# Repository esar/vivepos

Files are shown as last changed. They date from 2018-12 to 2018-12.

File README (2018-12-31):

This repository contains the PCB design and firmware for
a stanalone position sensor for use with the VIVE VR system.

 * 4 sensors, 30 positions/s each
 * Totally standalone, works out lighthouse positions for itself
 * No configuration, apply power... get position data
 * Accounts for gravity direction using accelerometer data from lighthouses
 * Output sent via USB serial and/or UART
 * Running on a 20MHz AVR

For latest version and full description, go to:
http://hacks.esar.org.uk/vive-position-sensor/

How to use:

1) Manufacture the board that can be found in the 'board' directory 
   (CADSoft Eagle format).
2) Edit Makefile and change paths to tools:
   CCDEVS, CCINC, CC, OBJCOPY, OBJDUMP
3) Run 'make' to build the firmware
4) Write firmware to board, e.g.:
   avrdude -c jtag2updi -P /dev/ttyACM1 -p m3209 -U flash:w:image.hex
5) Connect USB (or power+UART) to board
6) The board should start outputing position data shortly after
   the lighthouses become visible to it.
7) Use the solve-lighthouse.py script to pretty print the data stream:
   ./solve-lighthouse.py --dump-pos --dump-sensor=0 /dev/ttyACM0

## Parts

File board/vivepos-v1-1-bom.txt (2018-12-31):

Resistors (all 1% 0402 SMD)
===========================
33R        R7,R8,R21,R34,R35,R48,R57,R58,R71,R80,R81,R94
560R       R6,R33,R56,R79
100K       R17,R24,R25,R26,R44,R67,R90,R101,R102,R103
10K        R1,R2,R28,R29,R51,R52,R74,R75,R97,R98,R99,R100
12K        R18,R45,R68,R91
15K        R9,R14,R36,R41,R59,R64,R82,R87
1K         R11,R15,R27,R38,R42,R61,R65,R84,R88,R104
1K2        R23,R50,R73,R96
1K5        R4,R31,R54,R77
2K7        R12,R16,R39,R43,R62,R66,R85,R89
56K        R19,R20,R46,R47,R69,R70,R92,R93
5K6        R22,R49,R72,R95
6K8        R10,R13,R37,R40,R60,R63,R83,R86
8K2        R3,R5,R30,R32,R53,R55,R76,R78

Capacitors (Ceramic 0402 SMD)
=====================
100nF      C1,C2,C5,C7,C9,C11,C12,C13,C14,C15,C18,C20,C22,C24,C25,C26,C29,C31,C33,C35,C36,C37,C40,C42,C44,C46
100pF      C3,C10,C16,C23,C27,C34,C38,C45
1nF        C4,C6,C8,C17,C19,C21,C28,C30,C32,C39,C41,C43,C49,C50

Capacitors (other)
=================
2.2uF    Ceramic 0805                                                     C47
4.7uF    16V Tantalum (Kemet B45196E3475K209, no longer manufactured)     C48

Diodes
======
Photo-diode BPW32S             D1,D2,D3,D4
Schottky    PMEG3010EJ.115     D5,D6

Semiconductors
==============
Microcontroller ATMEGA3209     U$2
Quad Comparator LM339PT        IC2
Dual NPN/PNP    MBT3946DWDW    T13,T14,T15,T16,T17,T18,T19,T20,T21,T22,T23,T24
USB Serial      MCP2221        U$1
3V3 regulator   TPS76933DBVT   IC1

Connectors
==========
PINHD-1X2                     JP1
PINHD-1X3                     JP3
USB Amphenol 10103594-0001LF  JP2

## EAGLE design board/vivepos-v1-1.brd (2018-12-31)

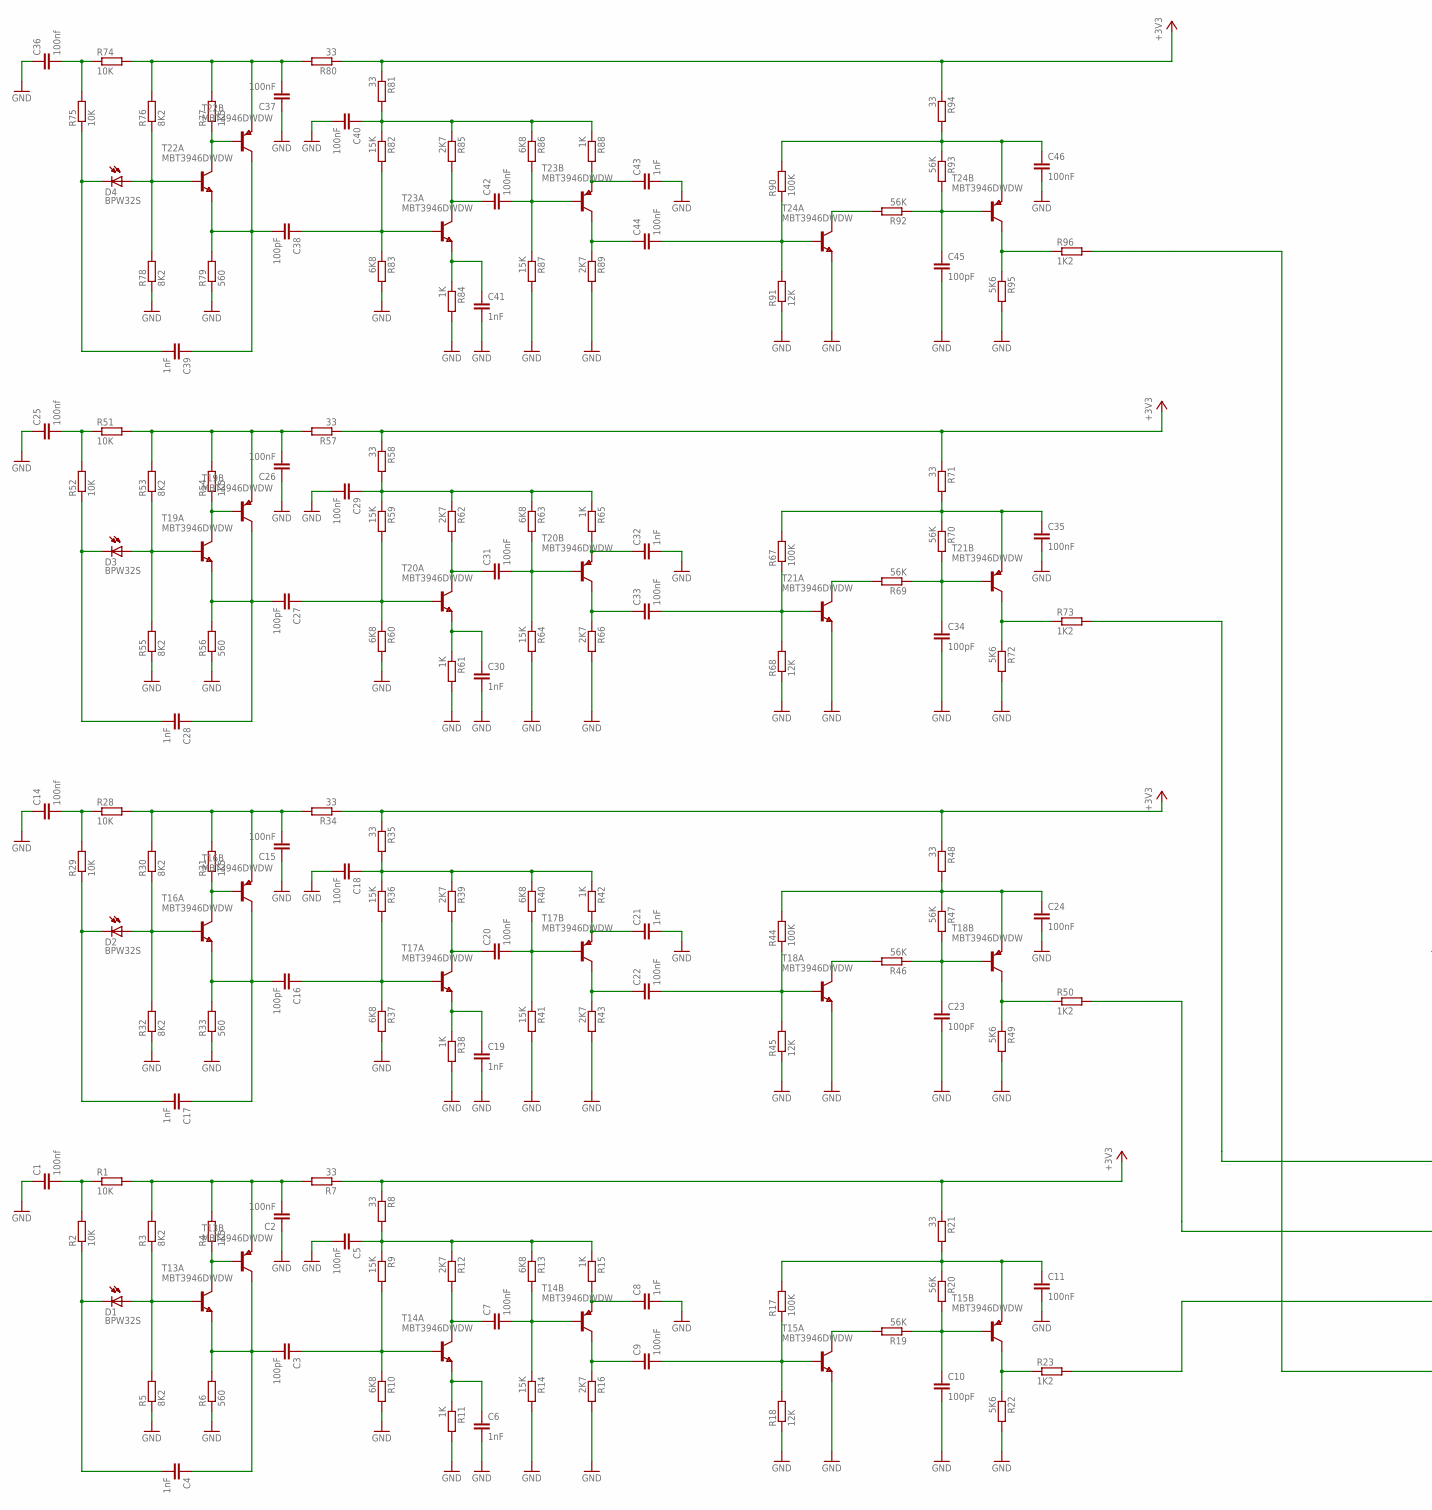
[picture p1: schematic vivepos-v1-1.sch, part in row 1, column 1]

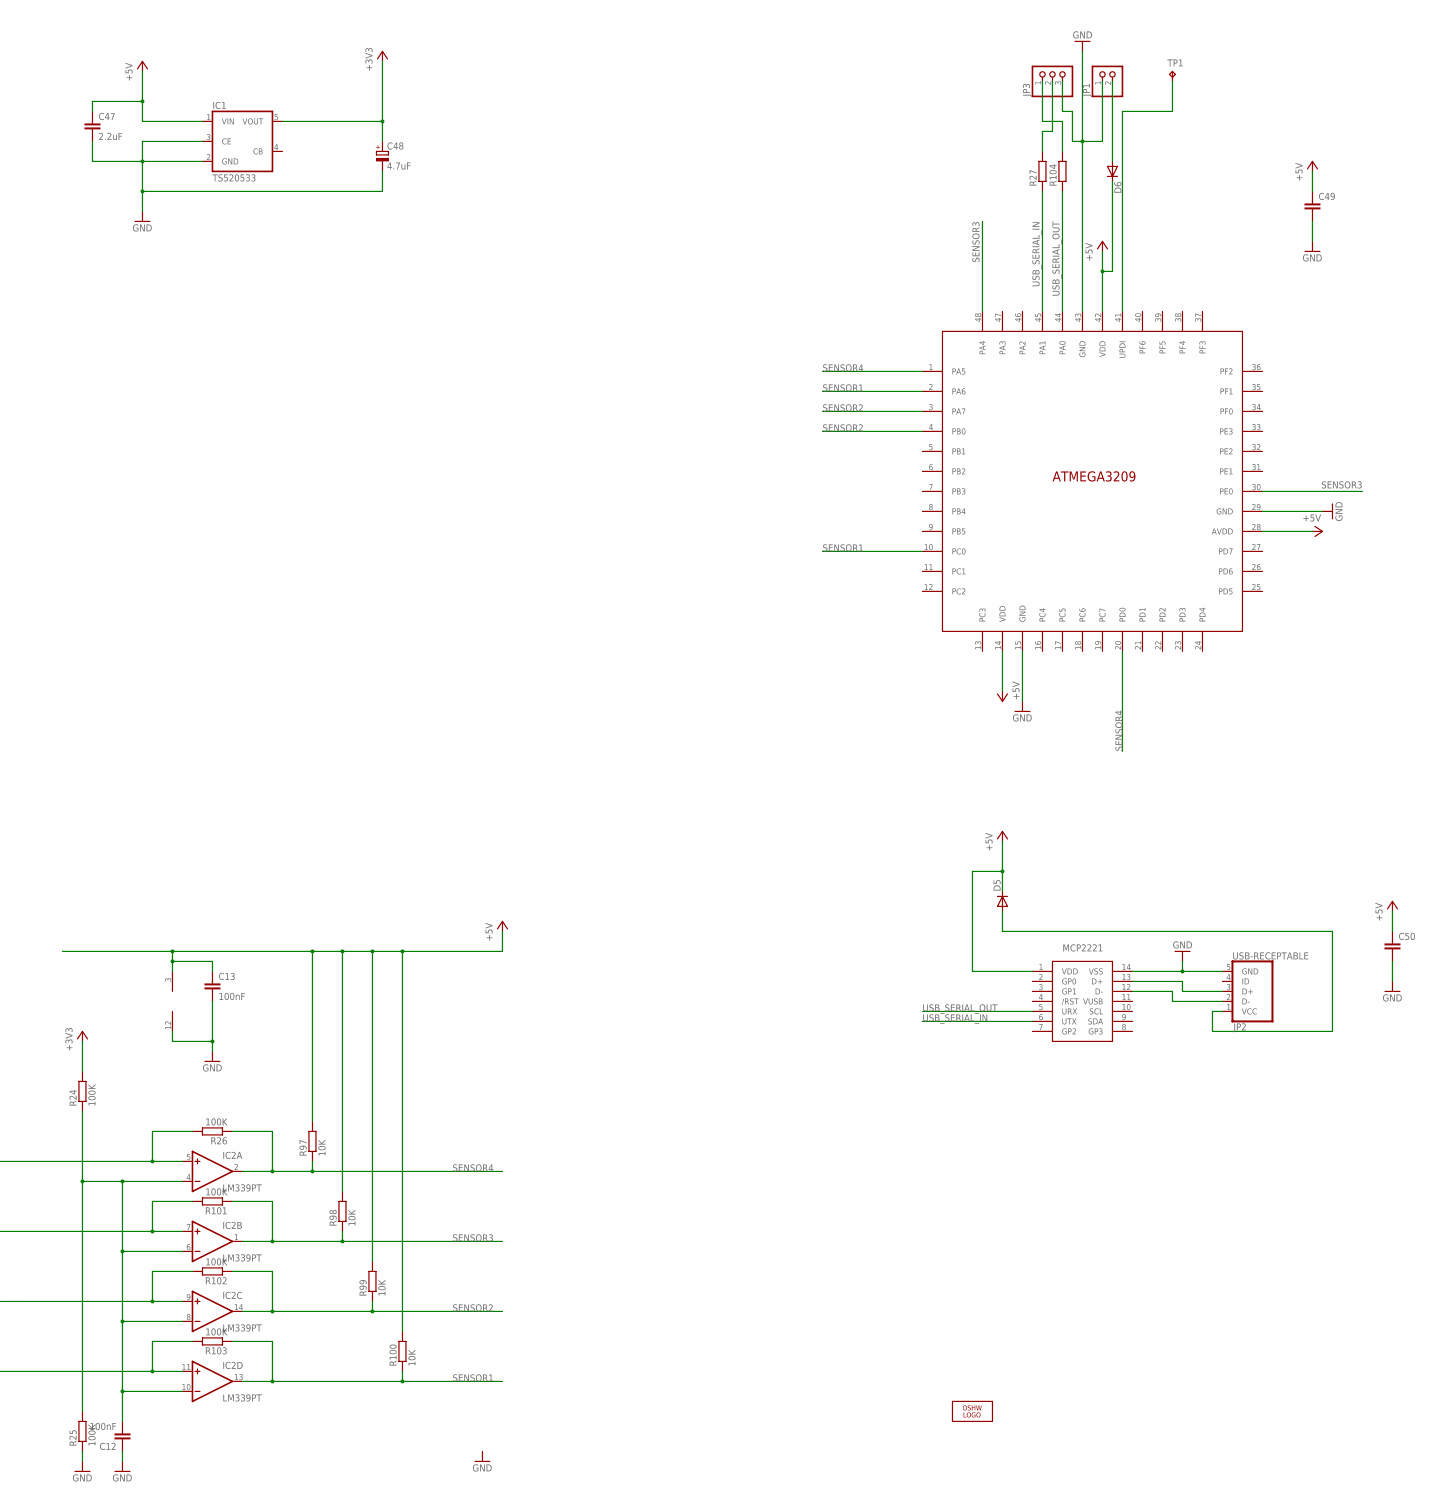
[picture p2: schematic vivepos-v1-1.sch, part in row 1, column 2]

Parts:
C1, C14, C25, C36: 100nf; C0402
C2, C5, C7, C9, C11, C12, C13, C15, C18, C20, C22, C24, C26, C29, C31, C33, C35, C37, C40, C42, C44, C46: 100nF; C0402
C3, C10, C16, C23, C27, C34, C38, C45: 100pF; C0402
C4, C6, C8, C17, C19, C21, C28, C30, C32, C39, C41, C43: 1nF; C0402
C47: 2.2uF; C0805
C48: 4.7uF; B/3528-21R
C49: C-EUC0402; C0402
C50: C-EUC0603; C0603
D1, D2, D3, D4: BPW32S; BPW34S
D5, D6: DIODE-SOD323-W; SOD323-W
IC1: TS520533; SOT25
IC2: LM339PT; TSSOP14
JP1: PINHD-1X2; 1X02
JP2: USB-RECEPTABLE; FCI-10103594-0001LF
JP3: PINHD-1X3; 1X03
LOGO1: OSHW_LOGO_FILLX0200-NT; OSHW_FILLX200_NOTEXT
R1, R2, R28, R29, R51, R52, R74, R75, R97, R98, R99, R100: 10K; R0402
R3, R5, R30, R32, R53, R55, R76, R78: 8K2; R0402
R4, R31, R54, R77: 1K5; R0402
R6, R33, R56, R79: 560; R0402
R7, R8, R21, R34, R35, R48, R57, R58, R71, R80, R81, R94: 33; R0402
R9, R14, R36, R41, R59, R64, R82, R87: 15K; R0402
R10, R13, R37, R40, R60, R63, R83, R86: 6K8; R0402
R11, R15, R38, R42, R61, R65, R84, R88: 1K; R0402
R12, R16, R39, R43, R62, R66, R85, R89: 2K7; R0402
R17, R24, R25, R26, R44, R67, R90, R101, R102, R103: 100K; R0402
R18, R45, R68, R91: 12K; R0402
R19, R20, R46, R47, R69, R70, R92, R93: 56K; R0402
R22, R49, R72, R95: 5K6; R0402
R23, R50, R73, R96: 1K2; R0402
R27, R104: R-EU_R0402; R0402
T13, T14, T15, T16, T17, T18, T19, T20, T21, T22, T23, T24: MBT3946DWDW; SOT363_PHILIPS
TP1: TPTP15R; TP15R
U$1: MCP2221; SOIC14
U$2: ATMEGA3209; TQFP48

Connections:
+3V3: C48.+, IC1.5 (VOUT), R7.1, R8.1, R21.1, R24.2, R34.1, R35.1, R48.1, R57.1, R58.1, R71.1, R80.1, R81.1, R94.1
+5V: C13.1, C47.1, C49.1, C50.1, D5.C, D6.C, IC1.1 (VIN), IC2.3 (V+), R97.2, R98.2, R99.2, R100.2, U$1.1 (VDD), U$2.14 (VDD), U$2.28 (AVDD), U$2.42 (VDD)
GND: C1.1, C2.1, C5.2, C6.2, C8.2, C10.2, C11.2, C12.1, C13.2, C14.1, C15.1, C18.2, C19.2, C21.2, C23.2, C24.2, C25.1, C26.1, C29.2, C30.2, C32.2, C34.2, C35.2, C36.1, C37.1, C40.2, C41.2, C43.2, C45.2, C46.2, C47.2, C48.-, C49.2, C50.2, IC1.2 (GND), IC1.3 (CE), IC2.12 (GND), JP1.1, JP2.5 (GND), JP3.3, R5.1, R6.1, R10.2, R11.2, R14.2, R16.2, R18.1, R22.2, R25.1, R32.1, R33.1, R37.2, R38.2, R41.2, R43.2, R45.1, R49.2, R55.1, R56.1, R60.2, R61.2, R64.2, R66.2, R68.1, R72.2, R78.1, R79.1, R83.2, R84.2, R87.2, R89.2, R91.1, R95.2, T15.1 (E), T18.1 (E), T21.1 (E), T24.1 (E), U$1.14 (VSS), U$2.15 (GND), U$2.29 (GND), U$2.43 (GND)
unnamed: C1.2, R1.1, R2.2
unnamed: C2.2, R1.2, R3.2, R4.2, R7.2, T13.4 (E)
unnamed: R4.1, T13.5 (B), T13.6 (C)
unnamed: D1.A, R3.1, R5.2, T13.2 (B)
unnamed: C3.2, C4.1, R6.2, T13.1 (E), T13.3 (C)
unnamed: C5.1, R8.2, R9.1, R12.1, R13.1, R15.1
unnamed: C3.1, R9.2, R10.1, T14.2 (B)
unnamed: C7.1, R12.2, T14.6 (C)
unnamed: C6.1, R11.1, T14.1 (E)
unnamed: C8.1, R15.2, T14.4 (E)
unnamed: C7.2, R13.2, R14.1, T14.5 (B)
unnamed: C9.1, R16.1, T14.3 (C)
unnamed: C4.2, D1.K (C), R2.1
unnamed: C9.2, R17.1, R18.2, T15.2 (B)
unnamed: C11.1, R17.2, R20.1, R21.2, T15.4 (E)
unnamed: C10.1, R19.1, R20.2, T15.5 (B)
unnamed: R19.2, T15.6 (C)
unnamed: R22.1, R23.1, T15.3 (C)
unnamed: IC2.9 (+IN), R23.2, R102.2
unnamed: C12.2, IC2.4 (-IN), IC2.6 (-IN), IC2.8 (-IN), IC2.10 (-IN), R24.1, R25.2
unnamed: C14.2, R28.1, R29.2
unnamed: D6.A, JP1.2
unnamed: C15.2, R28.2, R30.2, R31.2, R34.2, T16.4 (E)
unnamed: R31.1, T16.5 (B), T16.6 (C)
unnamed: D2.A, R30.1, R32.2, T16.2 (B)
unnamed: C16.2, C17.1, R33.2, T16.1 (E), T16.3 (C)
unnamed: D5.A, JP2.1 (VCC)
unnamed: C18.1, R35.2, R36.1, R39.1, R40.1, R42.1
unnamed: C16.1, R36.2, R37.1, T17.2 (B)
unnamed: C20.1, R39.2, T17.6 (C)
unnamed: C19.1, R38.1, T17.1 (E)
unnamed: C20.2, R40.2, R41.1, T17.5 (B)
unnamed: C21.1, R42.2, T17.4 (E)
unnamed: C22.1, R43.1, T17.3 (C)
unnamed: C17.2, D2.K (C), R29.1
unnamed: C22.2, R44.1, R45.2, T18.2 (B)
unnamed: C24.1, R44.2, R47.1, R48.2, T18.4 (E)
unnamed: C23.1, R46.1, R47.2, T18.5 (B)
unnamed: R46.2, T18.6 (C)
unnamed: R49.1, R50.1, T18.3 (C)
unnamed: C25.2, R51.1, R52.2
unnamed: C26.2, R51.2, R53.2, R54.2, R57.2, T19.4 (E)
unnamed: R54.1, T19.5 (B), T19.6 (C)
unnamed: D3.A, R53.1, R55.2, T19.2 (B)
unnamed: C27.2, C28.1, R56.2, T19.1 (E), T19.3 (C)
unnamed: TP1.TP, U$2.41 (UPDI)
unnamed: C29.1, R58.2, R59.1, R62.1, R63.1, R65.1
unnamed: C27.1, R59.2, R60.1, T20.2 (B)
unnamed: C31.1, R62.2, T20.6 (C)
unnamed: C30.1, R61.1, T20.1 (E)
unnamed: C31.2, R63.2, R64.1, T20.5 (B)
unnamed: C32.1, R65.2, T20.4 (E)
unnamed: C33.1, R66.1, T20.3 (C)
unnamed: C28.2, D3.K (C), R52.1
unnamed: C33.2, R67.1, R68.2, T21.2 (B)
unnamed: C35.1, R67.2, R70.1, R71.2, T21.4 (E)
unnamed: C34.1, R69.1, R70.2, T21.5 (B)
unnamed: R69.2, T21.6 (C)
unnamed: R72.1, R73.1, T21.3 (C)
unnamed: JP3.2, R27.2
unnamed: C36.2, R74.1, R75.2
unnamed: C37.2, R74.2, R76.2, R77.2, R80.2, T22.4 (E)
unnamed: R77.1, T22.5 (B), T22.6 (C)
unnamed: D4.A, R76.1, R78.2, T22.2 (B)
unnamed: C38.2, C39.1, R79.2, T22.1 (E), T22.3 (C)
unnamed: JP3.1, R104.2
unnamed: C40.1, R81.2, R82.1, R85.1, R86.1, R88.1
unnamed: C38.1, R82.2, R83.1, T23.2 (B)
unnamed: C42.1, R85.2, T23.6 (C)
unnamed: C41.1, R84.1, T23.1 (E)
unnamed: C42.2, R86.2, R87.1, T23.5 (B)
unnamed: C43.1, R88.2, T23.4 (E)
unnamed: C44.1, R89.1, T23.3 (C)
unnamed: C39.2, D4.K (C), R75.1
unnamed: C44.2, R90.1, R91.2, T24.2 (B)
unnamed: C46.1, R90.2, R93.1, R94.2, T24.4 (E)
unnamed: C45.1, R92.1, R93.2, T24.5 (B)
unnamed: R92.2, T24.6 (C)
unnamed: R95.1, R96.1, T24.3 (C)
unnamed: JP2.3 (D+), U$1.13 (D+)
unnamed: JP2.2 (D-), U$1.12 (D-)
unnamed: IC2.7 (+IN), R50.2, R101.2
unnamed: IC2.11 (+IN), R96.2, R103.2
unnamed: IC2.5 (+IN), R26.2, R73.2
SENSOR1: IC2.13 (OUT), R100.1, R103.1, U$2.2 (PA6), U$2.10 (PC0)
SENSOR2: IC2.14 (OUT), R99.1, R102.1, U$2.3 (PA7), U$2.4 (PB0)
SENSOR3: IC2.1 (OUT), R98.1, R101.1, U$2.30 (PE0), U$2.48 (PA4)
SENSOR4: IC2.2 (OUT), R26.1, R97.1, U$2.1 (PA5), U$2.20 (PD0)
USB_SERIAL_IN: R27.1, U$1.6 (UTX), U$2.45 (PA1)
USB_SERIAL_OUT: R104.1, U$1.5 (URX), U$2.44 (PA0)

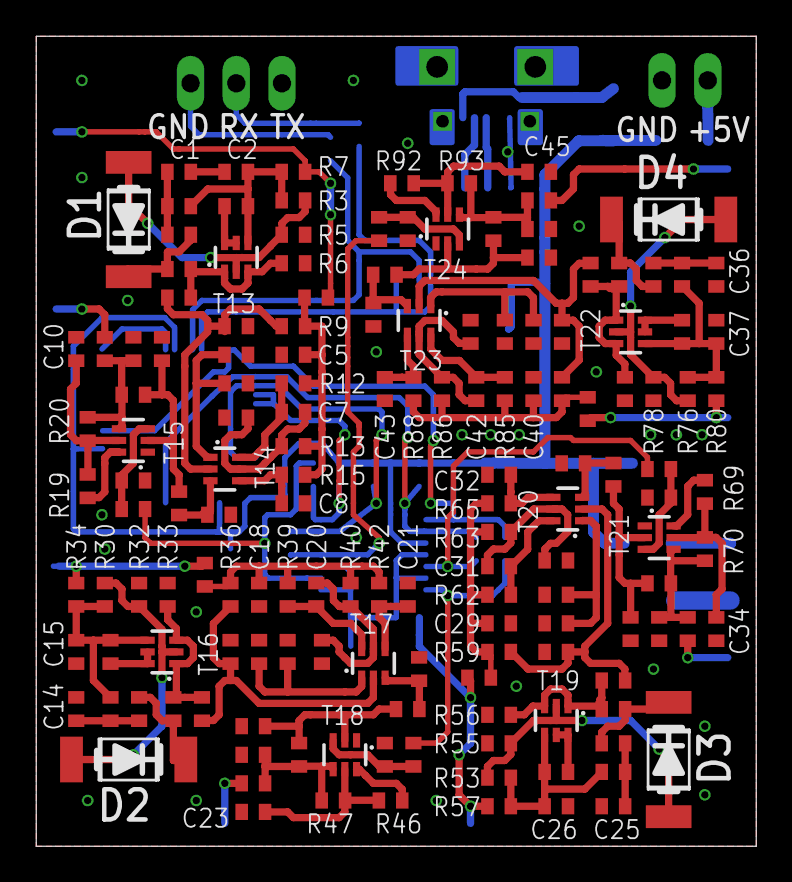
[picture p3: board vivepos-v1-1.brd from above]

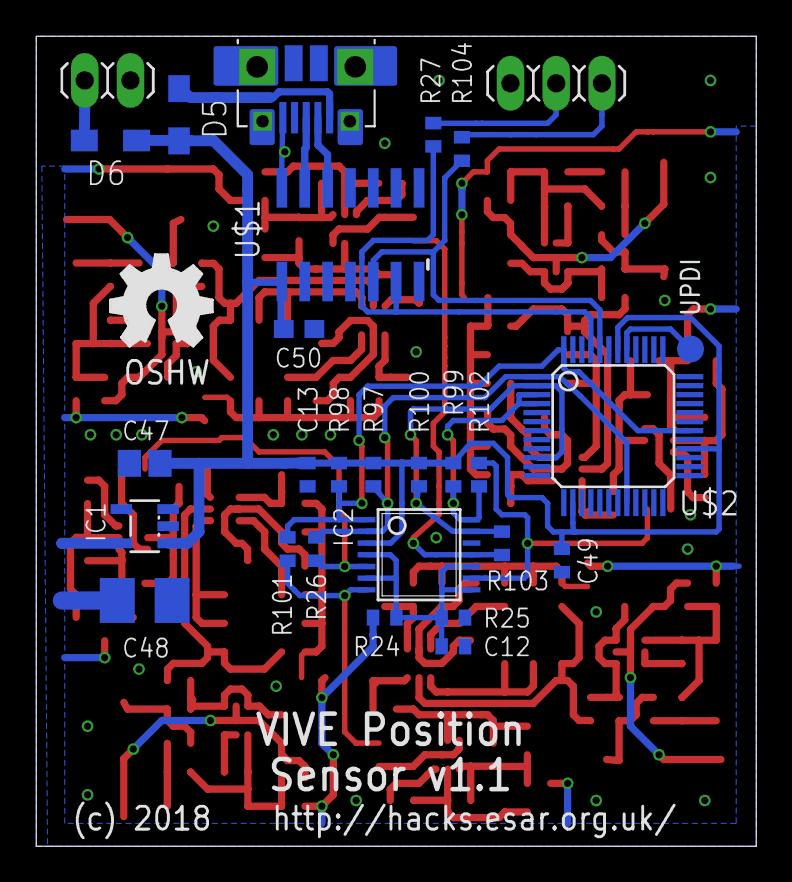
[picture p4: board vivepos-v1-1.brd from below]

Board: 2 copper layers, 40.0 x 45.0 mm, 181 parts (29 on the bottom side), 93 nets.

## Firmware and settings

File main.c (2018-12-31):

/*

   Copyright (C) 2018 Stephen Robinson
  
   This file is part of vivepos
  
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
*/

#include <string.h>
#include <stdio.h>
#include <math.h>

#include <avr/io.h>
#include <avr/interrupt.h>

#include "vivepos.h"
#include "uart.h"


#define SOLVE_LIGHTHOUSE_INTERVAL    1200 /*7200*/ /* 60 seconds */
#define SEND_LIGHTHOUSE_INTERVAL     1200  /*  5 seconds */

#define NUM_SOLUTIONS                2

#define SOLUTION_VALID()             (g_activeSolution < NUM_SOLUTIONS)

// TODO: Use RTC

static lighthouse_solution_t g_solutions[NUM_SOLUTIONS];
static uint8_t      g_activeSolution = -1;
static ootx_msg_t   g_lighthouseOotx[NUM_LIGHTHOUSES];
static sensor_t     g_sensors[NUM_SENSORS];
static uint16_t     g_sweepCount = 0;
static uint8_t      g_time = 0;



ISR(TCA0_OVF_vect)
{
	++g_time;
	TCA0.SINGLE.INTFLAGS |= 1;
}

// NOTE: TCBx.INTFLAGS is cleared by reading TCBx.CCMP
#define TCB_ISR(tcb, sensor)    \
	ISR(TCB##tcb##_INT_vect, ISR_NAKED) \
	{ \
		/* g_sensors[0].riseTime = TCB0.CCMP; */ \
		/* g_sensors[0].state = SENSOR_STATE_RISEN; */ \
		asm volatile( \
			       /* "sbi  0x15, 5         \n\t" */ \
			        "push r24             \n\t" \
			        "push r30             \n\t" \
			        "push r31             \n\t" \
			        "ldi  r30, lo8(%1)    \n\t"  /* Z = &g_sensors[x] */ \
			        "ldi  r31, hi8(%1)    \n\t" \
			        "lds  r24, %0         \n\t"  /* r24 = TCBx_CCMPL */ \
			        "std  Z+1, r24        \n\t" \
		       	        "lds  r24, %0+1       \n\t"  /* r24 = TCBx_CCMPH */ \
			        "std  Z+2, r24        \n\t" \
			        "ldi  r24, 1          \n\t"  /* r24 = SENSOR_STATE_RISEN */ \
			        "st   Z,   r24        \n\t" \
			        "pop  r31             \n\t" \
			        "pop  r30             \n\t" \
			        "pop  r24             \n\t" \
			       /* "cbi  0x15, 5         \n\t" */ \
			        "reti                 \n\t" \
			        : : "i" (_SFR_IO_ADDR(TCB##tcb##_CCMP)), "i" (&g_sensors[sensor])); \
	}
TCB_ISR(0, 1);
TCB_ISR(1, 0);
TCB_ISR(2, 3);
TCB_ISR(3, 2);


ISR(PORTA_PORT_vect)
{
	// grab the timer count and flags ASAP
	uint16_t count = TCB0.CNT;
	uint8_t  triggered = VPORTA.INTFLAGS;

//VPORTF.OUT |= 64;
	// clear the flags so we know if another edge
	// arrives while we're working
	VPORTA.INTFLAGS |= triggered;

	while(triggered)
	{
		// Make sure we've got all the rising edges first
		if(TCB0.INTFLAGS & 1)
			TCB0_INT_vect();
		if(TCB1.INTFLAGS & 1)
			TCB1_INT_vect();
		if(TCB2.INTFLAGS & 1)
			TCB2_INT_vect();
		if(TCB3.INTFLAGS & 1)
			TCB3_INT_vect();

		if(triggered & (1 << (4+2)))
		{
			if(g_sensors[0].state == SENSOR_STATE_RISEN)
			{
				g_sensors[0].fallTime = count;
				g_sensors[0].state = SENSOR_STATE_FALLEN;
			}
		}
		if(triggered & (1 << (4+3)))
		{
			if(g_sensors[1].state == SENSOR_STATE_RISEN)
			{
				g_sensors[1].fallTime = count;
				g_sensors[1].state = SENSOR_STATE_FALLEN;
			}
		}
		if(triggered & (1 << (4+0)))
		{
			if(g_sensors[2].state == SENSOR_STATE_RISEN)
			{
				g_sensors[2].fallTime = count;
				g_sensors[2].state = SENSOR_STATE_FALLEN;
			}
		}
		if(triggered & (1 << (4+1)))
		{
			if(g_sensors[3].state == SENSOR_STATE_RISEN)
			{
				g_sensors[3].fallTime = count;
				g_sensors[3].state = SENSOR_STATE_FALLEN;
			}
		}

		count = TCB0.CNT;
		triggered = VPORTA.INTFLAGS;
		VPORTA.INTFLAGS |= triggered;
	}
//VPORTF.OUT &= ~64;
}

// decodePulseWidth returns:
//     PULSE_TYPE_SWEEP (0x10)   for short sweep pulses
//     0x00 -> 0x07              for data from valid sync pulses
//     PULSE_TYPE_INVALID (0xf0) for pulses that are too long
//
// Pulse encoding info originally from: 
// https://github.com/nairol/LighthouseRedox/blob/master/docs/Light%20Emissions.md
//
//                      documented     observed     tick window with  
// skip | data | axis |  length uS | center ticks | (x - 309) / 51.2 
// -----+------+------+------------+--------------+-------------------
//    0 |    0 |    0 |       62.5 |    334 +/- 5 |       309 -> 359 
//    0 |    0 |    1 |       72.9 |    386 +/- 4 |       360 -> 410 
//    0 |    1 |    0 |       83.3 |    438 +/- 5 |       411 -> 461 
//    0 |    1 |    1 |       93.8 |    490 +/- 5 |       462 -> 512 
//    1 |    0 |    0 |      104.0 |    542 +/- 4 |       513 -> 563 
//    1 |    0 |    1 |      115.0 |    594 +/- 5 |       564 -> 615 
//    1 |    1 |    0 |      125.0 |    646 +/- 5 |       616 -> 666 
//    1 |    1 |    1 |      135.0 |    698 +/- 4 |       667 -> 717 
//
// Using 5Mhz clock, tick is 0.2uS
// 52 ticks between centers: (x * 5) / 256 = x / 51.2 = close enough
// width - 309 centers observed data in the length windows
//
uint8_t decodePulseWidth(int16_t width)
{
	uint8_t result;

	width = width - 296;
	if(width < 0)
		return PULSE_TYPE_SWEEP;
	result = ((width << 2) + width) >> 8;
	if(result > 7)
		result = PULSE_TYPE_INVALID;
	return result;
}

void ootxAddBit(ootx_t* ootx, uint8_t bit)
{
	if((bit & 1) && ootx->shiftRegister == 0 && ootx->frameBit == 0)
	{
		// got preamble
		ootx->pos = 0;
		ootx->length = 0;
		ootx->shiftCount = 0;
	}
	else if(ootx->shiftCount == 17)
	{
		ootx->shiftCount = 0;
		if((bit & 1) == 0)// || ootx->frameBit == 0)
			ootx->length = 0xff;  // abort

		// end of word
		if(ootx->length == 0)
		{
			ootx->length = (ootx->shiftRegister << 8) | (ootx->shiftRegister >> 8);
			ootx->length += 2;  // add checksum to length
		}
		else if(ootx->length != 0xff)
		{
			if(ootx->pos < ootx->length && ootx->pos < sizeof(ootx->data))
			{
				ootx->data[ootx->pos++] = ootx->shiftRegister >> 8;
				ootx->data[ootx->pos++] = ootx->shiftRegister & 0xFF;
			}
			else
			{
				// TODO: validate checksum
				ootx->validLength = ootx->length;
				ootx->length = 0xff;
			}
		}
	}

	ootx->frameBit = ootx->shiftRegister >> 15;
	ootx->shiftRegister = (ootx->shiftRegister << 1) | ((bit & 1));
	ootx->shiftCount = (ootx->shiftCount + 1);
}

uint8_t pollSensor(uint8_t sensorIndex)
{
	uint16_t now;
	sensor_t* sensor = &g_sensors[sensorIndex];

	if(sensor->state == SENSOR_STATE_RISEN)
	{
		now = TCA0.SINGLE.CNT;
		if(now - sensor->riseTime > SENSOR_TIMEOUT)
		{
			sensor->fallTime = sensor->riseTime + 1;
			sensor->state = SENSOR_STATE_FALLEN;
//printf("TOT\r\n");
//VPORTF.OUT |= 16;
//VPORTF.OUT &= ~16;
		}
	}

	if(sensor->state == SENSOR_STATE_FALLEN)
	{
		uint16_t riseTime;
		uint16_t width;
		uint8_t  data;

		riseTime = sensor->riseTime;
		width = sensor->fallTime - sensor->riseTime;
		sensor->state = SENSOR_STATE_IDLE;

		data = decodePulseWidth(width);

		//printf("%u, %u, %u, %u\r\n", sensorIndex, riseTime, width, data);

		if(data == PULSE_TYPE_INVALID)
		{
			printf("LRG %u\r\n", width);
			return 0;
		}

		if(data == PULSE_TYPE_SWEEP)
		{
			if(sensor->currentAngle < NUM_ANGLES)
			{
				uint16_t delta = riseTime - sensor->startTime;

				// note: compiler should reduce to angleTicks[sensor->currentAngle]
				sensor->angleTicks[sensor->currentAngle >> 1][sensor->currentAngle & 1] += delta;
 				sensor->angleTicks[sensor->currentAngle >> 1][sensor->currentAngle & 1] >>= 1;
				sensor->angleRadians[sensor->currentAngle >> 1][sensor->currentAngle & 1] = ((scalar_t)delta - SWEEP_CENTER_IN_TICKS) * (M_PI / SWEEP_180_IN_TICKS);
				              
				sensor->currentAngle = ANGLE_INVALID;
			}
		}
		else
		{
			uint16_t ticksSinceFirstPulse = riseTime - sensor->firstPulseTime;
			uint8_t lighthouse;

			if((ticksSinceFirstPulse >= MICROSECONDS_IN_TICKS(300) && 
			    ticksSinceFirstPulse <= MICROSECONDS_IN_TICKS(500)))
			{
				lighthouse = 1;
				sensor->firstPulseTime = riseTime - MICROSECONDS_IN_TICKS(400);
			}
			else
			{
				// Doesn't fit timing of second lighthouse, so it's either the first
				// or we're out of sync and might as well consider it the first
				lighthouse = 0;
				sensor->firstPulseTime = riseTime;
			}

			if(!PULSE_DATA_SKIP(data))
			{
				sensor->currentAngle = (lighthouse << 1) | PULSE_DATA_AXIS(data);
				sensor->startTime = riseTime;
			}

			ootxAddBit(&sensor->ootx[lighthouse], PULSE_DATA_DATA(data));
		}
	}
	else
	{
		now = TCA0.SINGLE.CNT;
		if(now - sensor->firstPulseTime > MICROSECONDS_IN_TICKS(8333 + 200))
		{
			// No pulse for more than 8333uS so move sensor->firstPulseTime
			// on by one cycle to try and stay locked while we're out of sight
			// of the lighthouses
			sensor->firstPulseTime += MICROSECONDS_IN_TICKS(8333);
		}
		else if(now - sensor->firstPulseTime > MICROSECONDS_IN_TICKS(600) &&
		        now - sensor->firstPulseTime < MICROSECONDS_IN_TICKS(800))
		{
			// Let the caller know that we're in the processing window
			// after the sync pulses where we don't expect more than one
			// further pulse (the sweep) in this cycle. This means we can
			// risk not being called for a while, because we won't miss
			// a pulse if more than one occur before we're next called

			// Also let them know which sweep we're on so that they
			// can synchronise processing angles when a whole set is
			// complete
			return sensor->currentAngle + 1;
		}
	}

	return 0;
}

scalar_t calcTotalTriangulationError(lighthouse_solution_t* solution)
{
	uint8_t i;
	vec3_t result;
	scalar_t distance;
	scalar_t total = 0;

	for(i = 0; i < NUM_SENSORS; ++i)
	{
		calcPosition(solution->lighthouses,
		             g_sensors[i].angleRadians[MASTER][AXIS0],
		             g_sensors[i].angleRadians[MASTER][AXIS1],
		             g_sensors[i].angleRadians[SLAVE][AXIS0],
		             g_sensors[i].angleRadians[SLAVE][AXIS1],
		             result,
		             &distance);
		total += fabs(distance);
	}

	return total;
}

uint8_t processWindowSolveLighthouse()
{
	static uint16_t last = 0;

	if(!SOLUTION_VALID() && g_sweepCount - last > SOLVE_LIGHTHOUSE_INTERVAL)
	{
		// Go ahead if we have everything that we need
		if(g_lighthouseOotx[0].length > 0 && 
		   g_lighthouseOotx[1].length > 0)
		{
			uint8_t index = (g_activeSolution + 1) % NUM_SOLUTIONS;

			printf("S:Solving\r\n");
//VPORTF.OUT |= 2;
			// Takes ~100mS to solve
			solveLighthouse(&g_solutions[index], g_sensors, g_lighthouseOotx);
//VPORTF.OUT &= ~2;

			if(g_solutions[index].totalError < (scalar_t)1.0)
				g_solutions[index].totalError = calcTotalTriangulationError(&g_solutions[index]);
			printf("S:Solution Error %.02f\r\n", g_solutions[index].totalError);

			if(g_solutions[index].totalError < (scalar_t)1.0)
			{
				printf("S:Running\r\n");
				g_activeSolution = index;
			}

			last = g_sweepCount;
			return 1;
		}

	}

	return 0;
}

void sendLighthouse(uint8_t index)
{
	printf("L:%u,%.1f,%.1f,%.1f,%f,%f,%f,%f,%f,%f,%f,%f,%f\r\n", index,
	       (float)g_solutions[g_activeSolution].lighthouses[index].origin[0],
	       (float)g_solutions[g_activeSolution].lighthouses[index].origin[1],
	       (float)g_solutions[g_activeSolution].lighthouses[index].origin[2],
	       (float)g_solutions[g_activeSolution].lighthouses[index].rotationMatrix[0],
	       (float)g_solutions[g_activeSolution].lighthouses[index].rotationMatrix[1],
	       (float)g_solutions[g_activeSolution].lighthouses[index].rotationMatrix[2],
	       (float)g_solutions[g_activeSolution].lighthouses[index].rotationMatrix[3],
	       (float)g_solutions[g_activeSolution].lighthouses[index].rotationMatrix[4],
	       (float)g_solutions[g_activeSolution].lighthouses[index].rotationMatrix[5],
	       (float)g_solutions[g_activeSolution].lighthouses[index].rotationMatrix[6],
	       (float)g_solutions[g_activeSolution].lighthouses[index].rotationMatrix[7],
	       (float)g_solutions[g_activeSolution].lighthouses[index].rotationMatrix[8]);
}

uint8_t processWindowSendLighthouse0()
{
	static uint16_t last = 0;

	if(SOLUTION_VALID() && g_sweepCount - last > SEND_LIGHTHOUSE_INTERVAL)
	{
		// for each lighthouse, approx:
		//     17 fixed chars
		//     7*3 = 21 position chars
		//     9*9 = 81 rotation chars
		// ~119 total bytes per send
		sendLighthouse(0);
		last = g_sweepCount;
		return 1;
	}

	return 0;
}

uint8_t processWindowSendLighthouse1()
{
	static uint16_t last = 0;

	if(SOLUTION_VALID() && g_sweepCount - last > SEND_LIGHTHOUSE_INTERVAL)
	{
		// for each lighthouse, approx:
		//     17 fixed chars
		//     7*3 = 21 position chars
		//     9*9 = 81 rotation chars
		// ~119 total bytes per send
		sendLighthouse(1);
		last = g_sweepCount;
		return 1;
	}

	return 0;
}

uint8_t processWindowSendLighthouseError()
{
	static uint16_t last = 0;

	if(SOLUTION_VALID() && g_sweepCount - last > SEND_LIGHTHOUSE_INTERVAL)
	{
		// ~33 total bytes per send
		printf("E:%.2f,%.2f,%.2f,%.2f,%.2f,%.2f\r\n",
		       (float)g_solutions[g_activeSolution].lighthouses[SLAVE].error.err01,
		       (float)g_solutions[g_activeSolution].lighthouses[SLAVE].error.err02,
		       (float)g_solutions[g_activeSolution].lighthouses[SLAVE].error.err03,
		       (float)g_solutions[g_activeSolution].lighthouses[SLAVE].error.err12,
		       (float)g_solutions[g_activeSolution].lighthouses[SLAVE].error.err13,
		       (float)g_solutions[g_activeSolution].lighthouses[SLAVE].error.err23);
		last = g_sweepCount;
		return 1;
	}

	return 0;
}

uint8_t processWindowCalcAndSendPos()
{
	static uint8_t sensorIndex = 0;
	vec3_t result;
	scalar_t distance;

	if(SOLUTION_VALID())
	{
//VPORTF.OUT |= 2;
		calcPosition(g_solutions[g_activeSolution].lighthouses,
		             g_sensors[sensorIndex].angleRadians[MASTER][AXIS0],
		             g_sensors[sensorIndex].angleRadians[MASTER][AXIS1],
		             g_sensors[sensorIndex].angleRadians[SLAVE][AXIS0],
		             g_sensors[sensorIndex].angleRadians[SLAVE][AXIS1],
		             result,
		             &distance);

		// 32 bytes per send
		printf("P:%u,%.1f,%.1f,%.1f,%.2f\r\n", 
		       sensorIndex,
		       (float)result[0], 
		       (float)result[1], 
		       (float)result[2], 
		       (float)distance);

		sensorIndex = (sensorIndex + 1) % 4;
//VPORTF.OUT &= ~2;

		return 1;
	}

	return 0;
}

// sends average of 29/4 = 7.25 bytes per sweep
uint8_t processWindowSendAngles()
{	
	uint8_t sensorIndex;

	for(sensorIndex = 0; sensorIndex < NUM_SENSORS; ++sensorIndex)
	{
		// 29 bytes per send
		printf("A:%u,%u,%u,%u,%u\r\n", 
		       sensorIndex, 
		       g_sensors[sensorIndex].angleTicks[MASTER][AXIS0], 
		       g_sensors[sensorIndex].angleTicks[MASTER][AXIS1],
		       g_sensors[sensorIndex].angleTicks[SLAVE][AXIS0],
		       g_sensors[sensorIndex].angleTicks[SLAVE][AXIS1]);
	}

	return 1;
}

uint8_t processWindowSaveOotx()
{
	uint8_t sensorIndex;
	uint8_t lighthouseIndex;
	uint8_t doneWork = 0;

	for(sensorIndex = 0; sensorIndex < NUM_SENSORS; ++sensorIndex)
	{
		for(lighthouseIndex = 0; lighthouseIndex < NUM_LIGHTHOUSES; ++lighthouseIndex)
		{
			ootx_t* ootx = &g_sensors[sensorIndex].ootx[lighthouseIndex];

			if(ootx->validLength)
			{
				g_lighthouseOotx[lighthouseIndex].length = ootx->validLength;
				memcpy(g_lighthouseOotx[lighthouseIndex].data, 
				       ootx->data, 
				       ootx->validLength);
				g_lighthouseOotx[lighthouseIndex].isNew = 1;
				ootx->validLength = 0;
				doneWork = 1;

				if(!SOLUTION_VALID())
					printf("S:Got OOTX %u\r\n", lighthouseIndex);
			}
		}
	}

	return doneWork;
}

uint8_t processWindowSendOotx()
{
	uint8_t lighthouseIndex;

	for(lighthouseIndex = 0; lighthouseIndex < NUM_LIGHTHOUSES; ++lighthouseIndex)
	{
		if(g_lighthouseOotx[lighthouseIndex].isNew)
		{
			uint8_t pos;

			// ~72 bytes per send
			printf("D:%u,%u,", 
			       lighthouseIndex, 
			       g_lighthouseOotx[lighthouseIndex].length);
			for(pos = 0; pos < g_lighthouseOotx[lighthouseIndex].length; ++pos)
				printf("%02x", g_lighthouseOotx[lighthouseIndex].data[pos]);
			printf("\r\n");
			g_lighthouseOotx[lighthouseIndex].isNew = 0;
			return 1;
		}
	}

	return 0;
}

int main()
{
	memset(g_sensors, 0, sizeof(g_sensors));

	CCP = 0xd8;             // enable protected register access
	CLKCTRL.MCLKCTRLB = 0;  // no clock prescaler, run at full 20MHz

	EVSYS.CHANNEL1 = EVSYS_GENERATOR_PORT1_PIN0_gc;  // PORTB0 -> CHANNEL1
	EVSYS.USERTCB0 = 2;                              // CHANNEL1 -> TCB0

	EVSYS.CHANNEL2 = EVSYS_GENERATOR_PORT0_PIN0_gc;  // PORTC0 -> CHANNEL2
	EVSYS.USERTCB1 = 3;                              // CHANNEL2 -> TCB1
	
	EVSYS.CHANNEL3 = EVSYS_GENERATOR_PORT1_PIN0_gc;  // PORTD0 -> CHANNEL3
	EVSYS.USERTCB2 = 4;                              // CHANNEL3 -> TCB2

	EVSYS.CHANNEL4 = EVSYS_GENERATOR_PORT0_PIN0_gc;  // PORTE0 -> CHANNEL4
	EVSYS.USERTCB3 = 5;                              // CHANNEL4 -> TCB3

	TCA0.SINGLE.CTRLA = 5;    // enable, CLK/4
	TCA0.SINGLE.INTCTRL = 1;  // enable overflow interrupt

	TCB0.CTRLB   = 2;  // input capture on event
	TCB0.EVCTRL  = 1;  // enable event, rising edge
	TCB0.INTCTRL = 1;  // enable capture interrupt
	TCB0.CTRLA   = 21; // enable, source TCA_CLK, synchronised to TCA

	TCB1.CTRLB   = 2;  // input capture on event
	TCB1.EVCTRL  = 1;  // enable event, rising edge
	TCB1.INTCTRL = 1;  // enable capture interrupt
	TCB1.CTRLA   = 21; // enable, source TCA_CLK, synchronised to TCA

	TCB2.CTRLB   = 2;  // input capture on event
	TCB2.EVCTRL  = 1;  // enable event, rising edge
	TCB2.INTCTRL = 1;  // enable capture interrupt
	TCB2.CTRLA   = 21; // enable, source TCA_CLK, synchronised to TCA

	TCB3.CTRLB   = 2;  // input capture on event
	TCB3.EVCTRL  = 1;  // enable event, rising edge
	TCB3.INTCTRL = 1;  // enable capture interrupt
	TCB3.CTRLA   = 21; // enable, source TCA_CLK, synchronsised to TCA

	TCA0.SINGLE.CTRLESET = 8; // Restart TCA and all synchronised TCBs to get same count in all

	PORTA.PIN4CTRL = 3; // interrupt on falling edge
	PORTA.PIN5CTRL = 3; // interrupt on falling edge
	PORTA.PIN6CTRL = 3; // interrupt on falling edge
	PORTA.PIN7CTRL = 3; // interrupt on falling edge

	PORTF.OUT=0;
	PORTF.DIR=64|32|16|8 |4|2|1;
	//PORTE.OUT=0;
	//PORTE.DIR=8;

	PORTA.OUT = 1;      // Make USART0 pins outputs
        PORTA.DIR = 0xF;
	uartInit();

	sei();

	printf("S:Waiting for OOTX\r\n");
	for(;;)
	{
		uint8_t inProcessingWindow;
		uint8_t sensorIndex;

//VPORTF.OUT |= 8;
		inProcessingWindow = 0;
		for(sensorIndex = 0; sensorIndex < NUM_SENSORS; ++sensorIndex)
		{
			uint8_t result = pollSensor(sensorIndex);
			if(result)
				inProcessingWindow = result;
		}

		if(inProcessingWindow)
		{
			// per sweep we transmit:
			//    item     |  average            | worst case
			//    ---------+---------------------+-----------
			//    position | 32 bytes            | 32 bytes
			//    angles   | 29/4 = 7.25 bytes   | 29 bytes
			//    ootx     | 72/322 = 0.2 bytes  | 72 bytes
			//    l'house  | 119/128 = 0.9 bytes | 119 bytes
			//    TOTAL    | 39.54 bytes         | 32+119 = 151 bytes
			//
			// average bytes/s: 39.54*240 = 9,490 bytes/s ~= 83Kbit/s
			// worst bytes/s: 151*240 = 36240 bytes/s ~= 318Kbit/s

			 
			// New positions need to be calculated every sweep to
			// be able to produce 30 positions per second for each
			// of the 4 sensors 
			processWindowCalcAndSendPos();

			if(inProcessingWindow == 1)
			{
				// In first sweep, we should have a whole set of angles
				// ready to be processed
				processWindowSendAngles();
			}
			else
			{
				// Use co-operative multitasking for the other
				// lower priority tasks
				(void)(processWindowSolveLighthouse() ||
				       processWindowSendLighthouse0() ||
				       processWindowSendLighthouse1() ||
				       processWindowSendLighthouseError() ||
				       processWindowSaveOotx() ||
				       processWindowSendOotx());
			}

			++g_sweepCount;
		}

//VPORTF.OUT &= ~8;
	}

	return 0;
}

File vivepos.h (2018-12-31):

/*

   Copyright (C) 2018 Stephen Robinson
  
   This file is part of vivepos
  
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
*/

#include <stdint.h>


#define F_TIMER              ((F_CPU) / 4)
#define MICROSECONDS_IN_TICKS(x) ((uint16_t)((x) / 0.2))

#define SWEEP_CENTER_IN_MICROSEC  4000
#define SWEEP_180_IN_MICROSEC     8333
#define SWEEP_CENTER_IN_TICKS     MICROSECONDS_IN_TICKS(SWEEP_CENTER_IN_MICROSEC)
#define SWEEP_180_IN_TICKS        MICROSECONDS_IN_TICKS(SWEEP_180_IN_MICROSEC)

#define NUM_SENSORS          4

#define PULSE_TYPE_SYNC      0x00
#define PULSE_TYPE_SWEEP     0x10
#define PULSE_TYPE_INVALID   0xf0
#define PULSE_HAS_DATA(x)    (((x) & 0xF0) == 0)
#define PULSE_DATA_AXIS(x)   ((x) & 1)
#define PULSE_DATA_DATA(x)   (((x) >> 1) & 1)
#define PULSE_DATA_SKIP(x)   (((x) >> 2) & 1)
#define PULSE_DATA_INVALID   0xFF

#define ANGLE_INVALID        0xFF

#define SENSOR_TIMEOUT       1000

#define SENSOR_STATE_IDLE    0
#define SENSOR_STATE_RISEN   1
#define SENSOR_STATE_FALLEN  2

#define NUM_LIGHTHOUSES      2
#define NUM_AXES             2
#define NUM_ANGLES           (NUM_LIGHTHOUSES * NUM_AXES)

#define OOTX_MAX_DATA        0x30

#define MASTER               0
#define SLAVE                1
#define AXIS0                0
#define AXIS1                1

#ifndef TRUE
#define TRUE 1
#endif

#ifndef FALSE
#define FALSE 0
#endif

//typedef _Accum scalar_t;
typedef float scalar_t;

typedef scalar_t vec3_t[3];
typedef scalar_t vec4_t[4];
typedef scalar_t vec6_t[6];

typedef scalar_t mat3_3_t[9];
typedef scalar_t mat4_4_t[16];
typedef scalar_t mat4_6_t[24];
typedef scalar_t mat6_4_t[24];


typedef struct
{
	scalar_t err01, err02, err03, err12, err13, err23, total;

} solution_error_t;

typedef struct
{
	scalar_t rotationMatrix[9];
	vec3_t origin;
	solution_error_t error;

} lighthouse_t;

typedef struct
{
	lighthouse_t lighthouses[NUM_LIGHTHOUSES];
	scalar_t totalError;

} lighthouse_solution_t;

typedef struct
{
	uint16_t fw_version;
	uint32_t id;
	uint16_t fcal_0_phase;
	uint16_t fcal_1_phase;
	uint16_t fcal_0_tilt;
	uint16_t fcal_1_tilt;
	uint8_t  sys_unlock_count;
	uint8_t  hw_version;
	uint16_t fcal_0_curve;
	uint16_t fcal_1_curve;
	int8_t   accel_dir_x;
	int8_t   accel_dir_y;
	int8_t   accel_dir_z;
	uint16_t fcal_0_gibphase;
	uint16_t fcal_1_gibphase;
	uint16_t fcal_0_gibmag;
	uint16_t fcal_1_gibmag;
	uint8_t  mode_current;
	uint8_t  sys_faults;

} ootx_msg_v6_t;

typedef struct
{
	uint8_t  pos;
	uint16_t length;
	uint8_t  shiftCount;
	uint16_t shiftRegister;
	uint8_t  frameBit;
	uint8_t  validLength;
	uint8_t  data[OOTX_MAX_DATA];

} ootx_t;

typedef struct
{
	uint8_t isNew;
	uint8_t length;
	union
	{
		uint8_t data[OOTX_MAX_DATA];
		ootx_msg_v6_t msg;
	};

} ootx_msg_t;

typedef struct
{
	volatile uint8_t  state;
	volatile uint16_t riseTime;
	volatile uint16_t fallTime;

	uint16_t angleTicks[NUM_LIGHTHOUSES][NUM_AXES];
	scalar_t angleRadians[NUM_LIGHTHOUSES][NUM_AXES];
	uint16_t startTime;
	uint16_t firstPulseTime;
	uint8_t  currentAngle;

	ootx_t ootx[NUM_LIGHTHOUSES];

} sensor_t;

void solveLighthouse(lighthouse_solution_t* solution, sensor_t* sensors, ootx_msg_t* ootx);

uint8_t calcPosition(lighthouse_t* lighthouses,
                     scalar_t angle1, scalar_t angle2, 
                     scalar_t angle3, scalar_t angle4,
                     vec3_t result, scalar_t* distance);

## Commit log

2018-09-06 separate OOTX buffers for each sensor and each lighthouse
2018-09-06 don't block in printf
2018-09-14 solve-lighthouse.py: fix constant names
    [solve-lighthouse.py]
2018-09-16 update firmware to calculate and send position update firmware to only calc/send in processing window after sync pulses to avoid missed pulses fix wrong rotation matrix from solver change solver to u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
    [main.c, solve-lighthouse.py]
2018-09-16 swap debug timeout printf for pin toggle
    [main.c]
2018-09-16 Fix processing window comment
    [main.c]
2018-09-16 fix cos/sin in solve-lighthouse.py after removing sympy import
    [solve-lighthouse.py]
2018-12-28 update code for v1.1 board
2018-12-28 Add missing total error calculation
    [main.c]
2018-12-29 Detect and fix bad lighthouse solutions (lighthouse below sensor plane, sensor plane behind lighthouse)
2018-12-31 Added PCB to repo
    [vivepos-v1-1.brd, vivepos-v1-1.sch]
2018-12-31 Added BOM

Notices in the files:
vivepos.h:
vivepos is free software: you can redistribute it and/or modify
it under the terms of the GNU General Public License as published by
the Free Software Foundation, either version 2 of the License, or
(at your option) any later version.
